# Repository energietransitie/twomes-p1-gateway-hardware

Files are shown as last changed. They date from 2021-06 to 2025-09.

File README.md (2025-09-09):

# Twomes P1 Gateway Hardware

This repository contains the open hardware design files for the Twomes P1 Gateway device, which can read measurement data from a smart meter adhering to the Dutch Smart Meter Requirements (DSMR). It can also receive data from various other Twomes 'satellite' measurement devices via the [ESP-NOW](https://www.espressif.com/en/products/software/esp-now/overview) protocol. The Twomes P1 Gateway can upload this measurement data to a Twomes server via Wi-Fi using secure HTTPS.

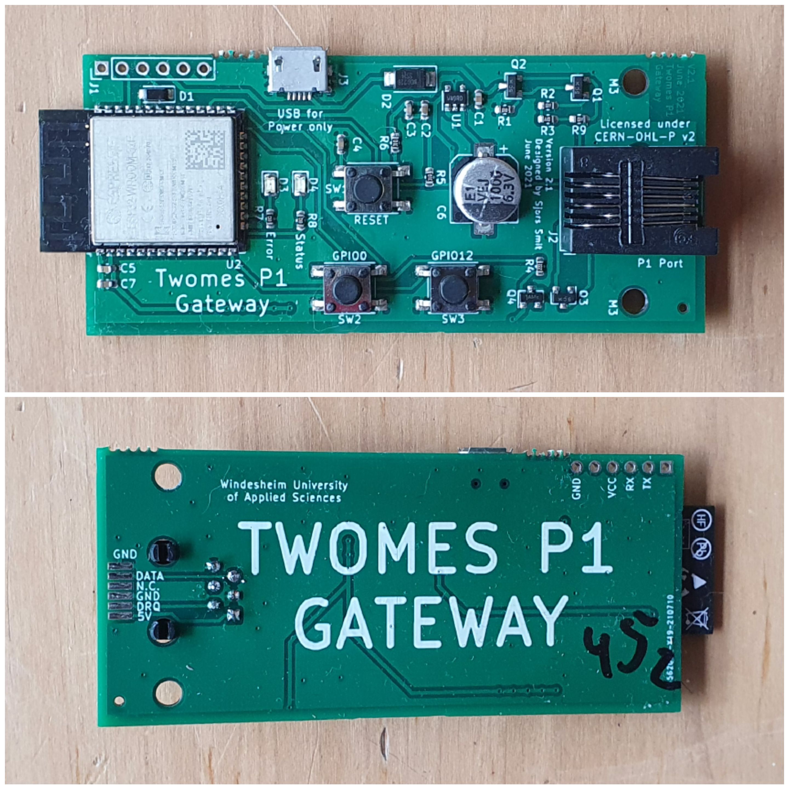
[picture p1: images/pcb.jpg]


## Table of contents
* [General info](#general-info)
* [Producing](#producing)
* [Developing](#developing) 
* [Features](#features)
* [Status](#status)
* [License](#license)
* [Citation](#citation)
* [Credits](#credits)

## General info
This repository contains the source files and fabrication files of the hardware designs of the Twomes P1 Gateway device and its enclosure. It also includes a `docs` folder with recent printouts of the [schematics](./docs/twomes-p1-gateway-sch.pdf) and [PCB layout](./docs/twomes-p1-gateway-pcb.pdf). 

You can run different kinds of firmware on this device:
- [twomes-p1-reader-firmware](https://github.com/energietransitie/twomes-p1-reader-firmware), if you need it to work on a server that supports v2 of the Twomes API.
- [twomes-p1-gateway-firmware](https://github.com/energietransitie/twomes-p1-gateway-firmware), if you need the device to serve as a gateway for the [twomes-room-monitor](https://github.com/energietransitie/twomes-room-monitor-firmware) and/or [twomes-boiler-monitor](https://github.com/energietransitie/twomes-boiler-monitor-firmware).

## Producing

### Printed Circuit Board
To fabricate the printed circuit board you can use various PCB services. 

The folder [pcb/jlcpcb](./pcb/jlcpcb) includes all exported files needed to have the PCBs manufactured by [JLCPCB](https://www.jlcpcb.com). Upload the [zipped gerber files](./pcb/jlcpcb/gerber-TwomesGateway.zip) to the [JLCPCB quote page](https://cart.jlcpcb.com/quote), select the amount of PCBs and a colour for the silkscreen. All other options can be left on default. If SMT assembly is desired, also select this option before ordering. This will take you to a page where the BOM and POS file can be uploaded. Use the files [BOM-TwomesGateway.csv](./pcb/jlcpcb/assembly/BOM-TwomesGateway.csv) and [CPL-TwomesGateway.csv](./pcb/jlcpcb/assembly/BOM-TwomesGateway.csv).

N.B. All components marked "DO NOT PLACE" in the BOM-*.csv file can not be ordered from JLCPCB and need to be ordered from other services and placed manually.

### Enclosure
To fabricate the enclosure you can use your own 3D printer or use a 3D printing service. 

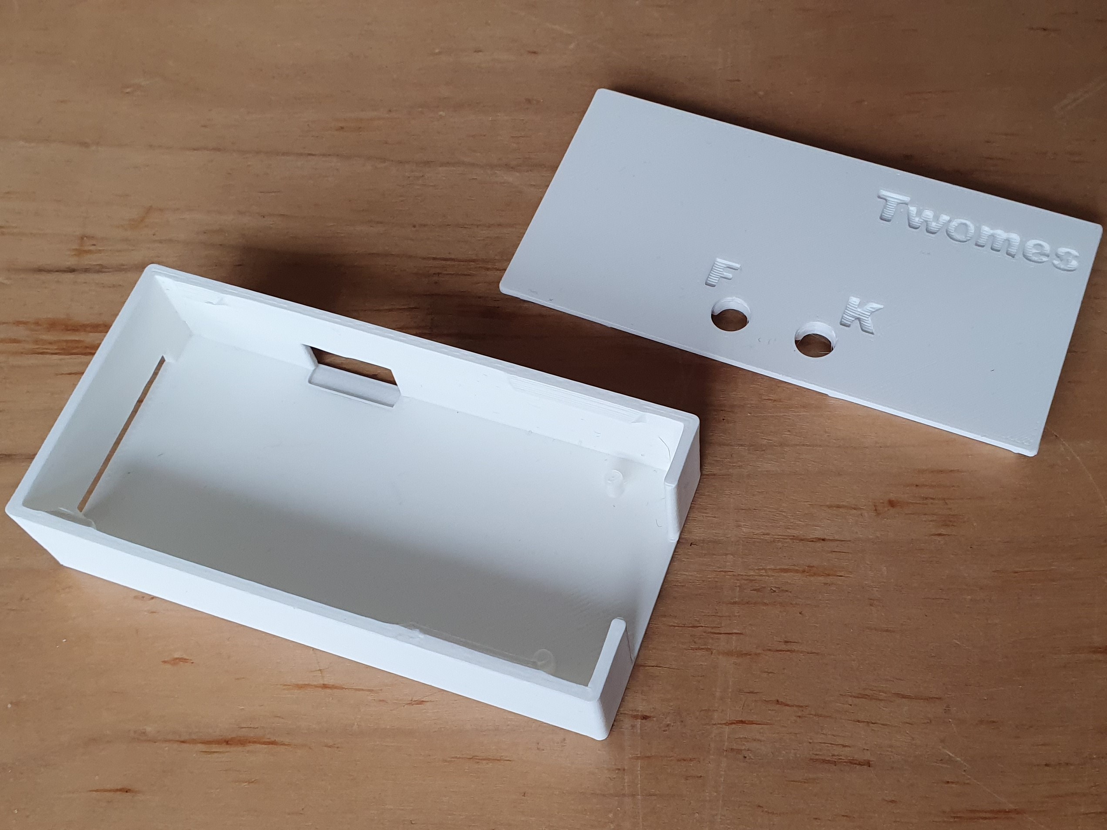
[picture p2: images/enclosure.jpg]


The folder [enclosure/fabrication](./enclosure/fabrication) contains exported STL files for the [case](./enclosure/fabrication/twomes-p1-gateway-enclosure-case.stl), the [lid](./enclosure/fabrication/twomes-p1-gateway-enclosure-lid.stl) and the [button](./enclosure/fabrication/twomes-p1-gateway-enclosure-button.stl) of the Twomes P1-gateway enclosure. The STL files can be imported into any slicer and turned into G-Code for a 3D printer.

## Developing

### Printed Circuit Board
To change the hardware design of the PCB, you need:
* [KiCad](https://www.kicad.org/download/) installed to change te PCB design. 

The KiCad source files of the PCB can be found in the folder [pcb](./pcb).

To convert the PCBs into a format suitable for fabrication, consult the webpage of your PCB manufacturer of choice. For example, see the [JLCPCB guide on how to export Gerbers](https://support.jlcpcb.com/article/149-how-to-generate-gerber-and-drill-files-in-kicad) and the  [JLCPCB guide how to export the BOM and POS files](https://support.jlcpcb.com/article/84-how-to-generate-the-bom-and-centroid-file-from-kicad). You may also use a KiCad plug-in for this purpose such as [kicad-jlcpcb-tools](https://github.com/Bouni/kicad-jlcpcb-tools).

### Enclosure
To change the hardware design of the enclosure, you need either:
* [Autodesk Fusion 360](https://www.kicad.org/download/) installed (Autodesk provides 30 day free trials and [free one-year educational access](https://www.autodesk.com/education/edu-software/overview?sorting=featured&filters=individual) to its products and services for eligible students, teachers and research staff); 
* or [FreeCAD](https://www.freecadweb.org/), an open source alternative.

The source files of the enclosure can be found in the folder [enclosure](./enclosure). We include both .f3d source files and .step source files we obtained after conversion.
## Features
The Twomes P1 Gateway features the following main hardware components:
* [ESP32-WROOM-32E](https://www.espressif.com/sites/default/files/documentation/esp32-wroom-32e_esp32-wroom-32ue_datasheet_en.pdf) module;
* female RJ12 connector for connection to the P1 port of a smart meter adhering to the Dutch Smart Meter Requirements (smart meters compatible with DSMR v5 provide enough power for the Twomes P1 gateway);
* micro USB input for a 5 V power supply (only needed for smart meters adhering to DSMR v4 and lower);
* FTDI compatible serial programming header (3.3 V).

## Status
Project is: _in progress_

## License
The hardware designs in this repository are available under the [CERN-OHL-P v2 license](./LICENSE), Copyright 2022 [Research group Energy Transition, Windesheim University of Applied Sciences](https://windesheim.nl/energietransitie)

## Citation

If you use this repository in your research or work, please cite the following pre-print, which describes the overall NeedForHeat DataGear system of which this repository is a part:

> Ter Hofte, H., & van Ravenzwaaij, N. (2025). *NeedForHeat DataGear: An Open Monitoring System to Accelerate the Residential Heating Transition*. arXiv preprint arXiv:2509.06927. https://doi.org/10.48550/arXiv.2509.06927

**Note:** This is a pre-print submitted on 8 Sep 2025 and has not yet been peer-reviewed. For the full paper, see [https://arxiv.org/abs/2509.06927](https://arxiv.org/abs/2509.06927).

## Credits
This open hardware design made by:
* Sjors Smit · [@Shorts1999](https://github.com/Shorts1999)

Thanks also go to:
* Fredrik-Otto Lautenbag ·  [@Fredrik1997](https://github.com/Fredrik1997)
* Gerwin Buma ·  [@GerwinBuma](https://github.com/GerwinBuma) 
* Marco Winkelman · [@MarcoW71](https://github.com/MarcoW71)

Product owner:
* Marco Winkelman · [@MarcoW71](https://github.com/MarcoW71)

We use and gratefully acknowlegde the efforts of the makers of:
* [KiCad Libraries](https://kicad.github.io/), by the KiCad Development Team, licensed under [an adapted version of the CC-BY-SA 4.0 License](https://www.kicad.org/libraries/license/)

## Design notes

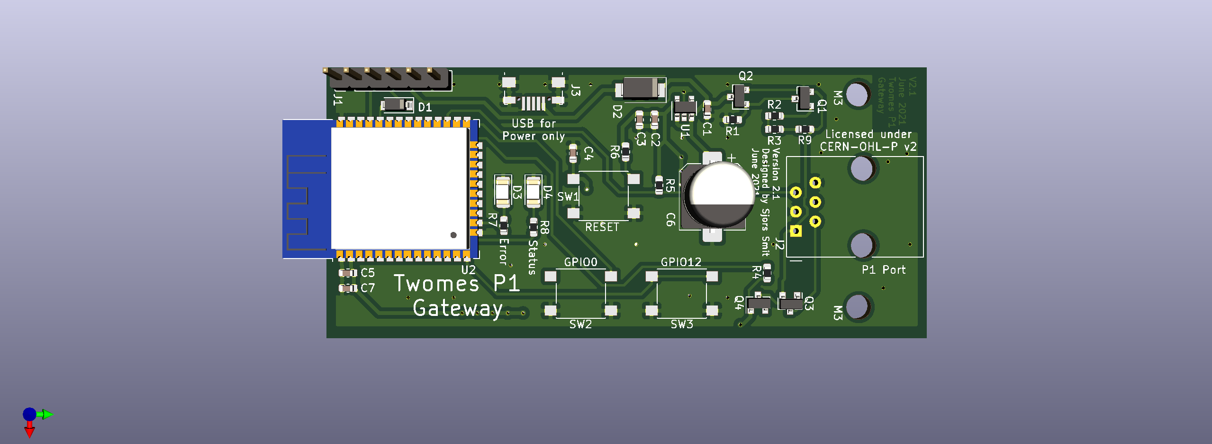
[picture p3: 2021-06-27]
images/twomes-p1-gateway-pcb-top.png

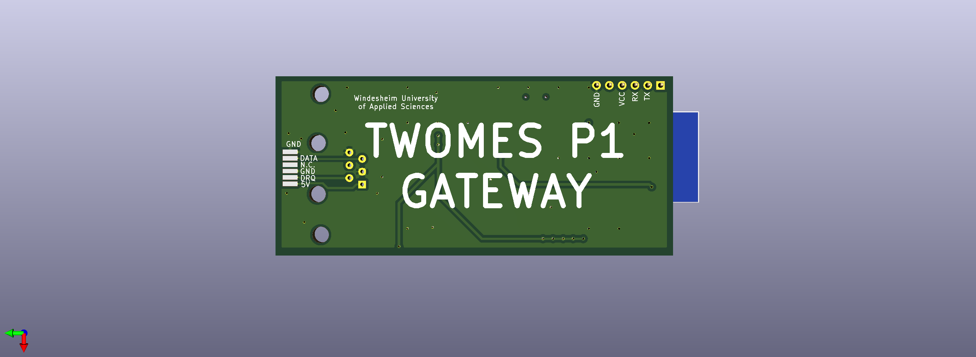
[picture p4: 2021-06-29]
images/twomes-p1-gateway-pcb-3d-bottom.png

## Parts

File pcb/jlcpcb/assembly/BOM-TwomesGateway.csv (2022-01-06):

Comment | Designator | Footprint | LCSC
1uF | C1,C2 | Capacitor_SMD:C_0603_1608Metric | C15849
10uF | C7 | Capacitor_SMD:C_0603_1608Metric | C19702
100nF | C3,C4,C5 | Capacitor_SMD:C_0603_1608Metric | C14663
1000uF | C6 | Capacitor_SMD:CP_Elec_8x10.5 | C134755
1N4148W | D1 | Diode_SMD:D_SOD-123 | C81598
SS14 | D2 | Diode_SMD:D_SMA | C2480
LED_RED | D3 | LED_SMD:LED_1206_3216Metric | C84256
LED_GREEN | D4 | Diode_SMD:D_0805_2012Metric | C2297
FTDI header | J1 | Connector_PinHeader_2.54mm:PinHeader_1x06_P2.54mm_Vertical | DO NOT PLACE
RJ12-6P6C | J2 | Connector_RJ:RJ12_Amphenol_54601 | DO NOT PLACE
USB_B_Micro | J3 | Connector_USB:USB_Micro-B-SHOUHAN_QTJ | C404968
BC807 | Q1,Q2,Q3 | Package_TO_SOT_SMD:SOT-23 | C82369
MMBT3904 | Q4 | Package_TO_SOT_SMD:SOT-23 | C20526
1k | R1,R7,R8 | Resistor_SMD:R_0603_1608Metric | C21190
1R | R2,R3,R9 | Resistor_SMD:R_0603_1608Metric | C22936
2.2k | R4 | Resistor_SMD:R_0603_1608Metric | C4190
10k | R5,R6 | Resistor_SMD:R_0603_1608Metric | C25804
SW_Push | SW1,SW2,SW3 | Button_Switch_SMD:SW_Push_1P1T_NO_6x6mm_H9.5mm | C83206
AP7365-33WG-7 | U1 | Package_TO_SOT_SMD:SOT-23-5 | C150742
ESP32-WROOM-32E | U2 | RF_Module:ESP32-WROOM-32 | C701343

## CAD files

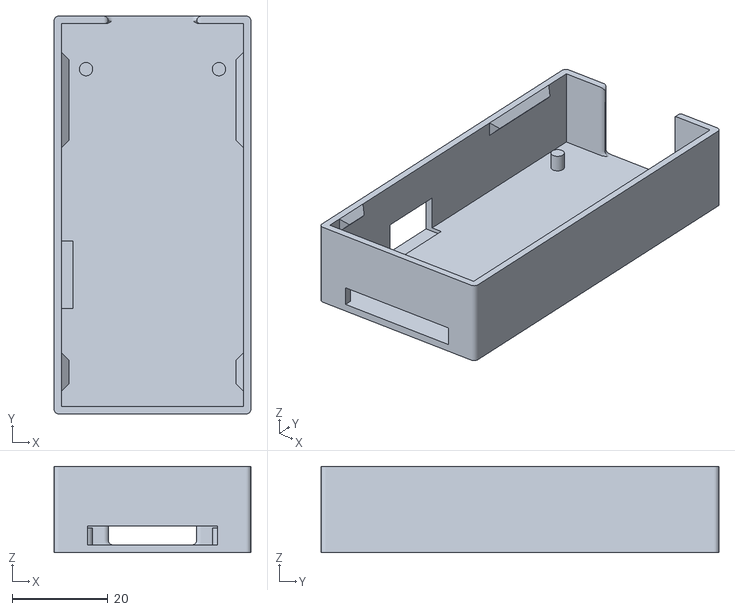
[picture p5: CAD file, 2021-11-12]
enclosure/fabrication/twomes-p1-gateway-enclosure-case.stl
41.2 x 83.2 x 18.0

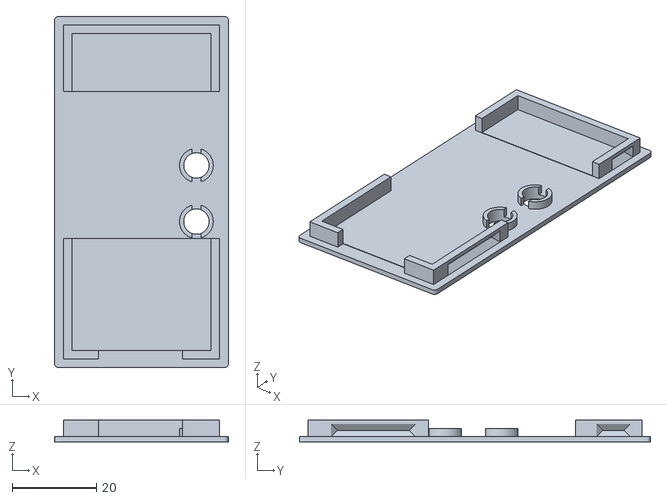
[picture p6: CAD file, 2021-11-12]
enclosure/fabrication/twomes-p1-gateway-enclosure-lid.stl
41.2 x 83.2 x 5.10

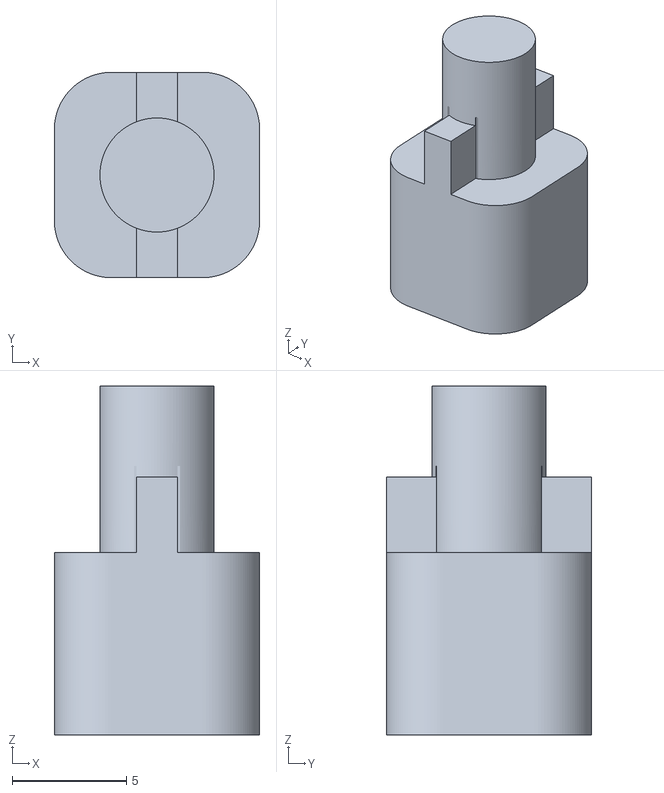
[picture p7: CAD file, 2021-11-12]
enclosure/fabrication/twomes-p1-gateway-enclosure-button.stl
9.00 x 9.00 x 15.3

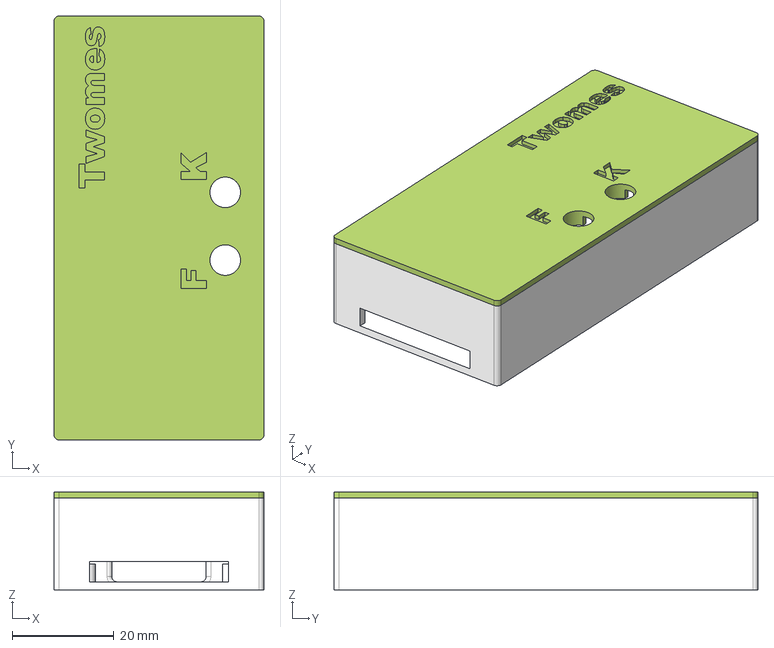
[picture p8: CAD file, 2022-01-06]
enclosure/twomes-p1-gateway-enclosure.step
41.2 x 83.2 x 19.2 mm

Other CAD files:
enclosure/twomes-p1-gateway-enclosure-case.step
enclosure/twomes-p1-gateway-enclosure-lid.step
enclosure/twomes-p1-gateway-button.step
enclosure/twomes-p1-gateway-button.f3d
enclosure/twomes-p1-gateway-enclosure.f3d

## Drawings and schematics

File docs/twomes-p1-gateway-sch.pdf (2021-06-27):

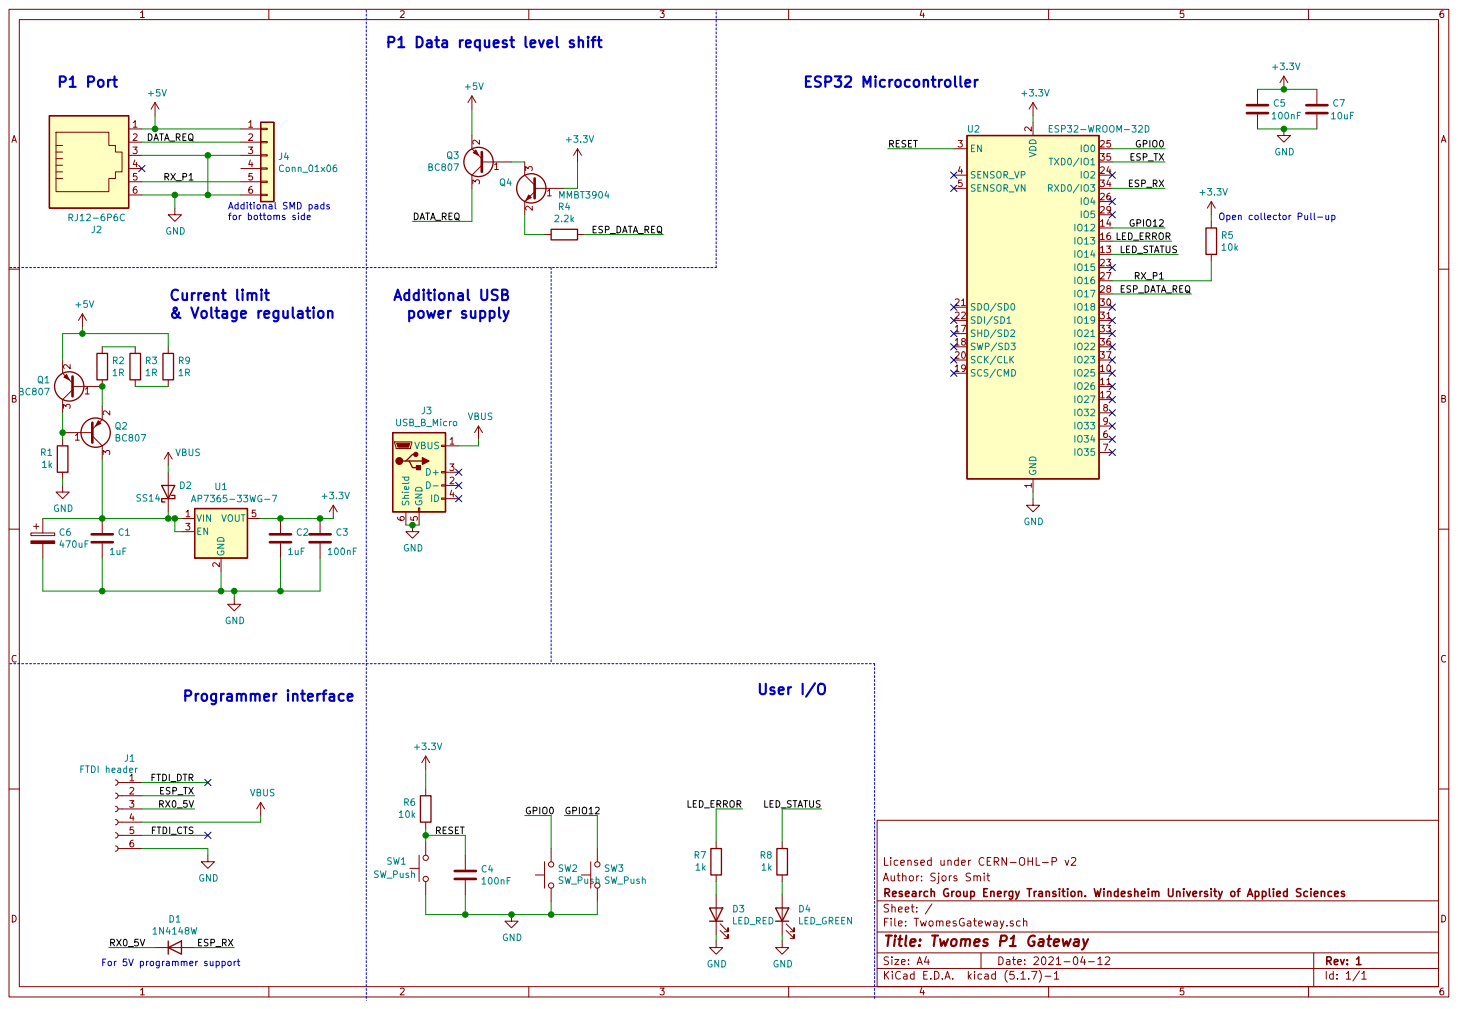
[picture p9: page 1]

P1 Data request level shift

2 SCK/CLK 20 SDO/SD0 21 SDI/SD1 22

Open collector Pull-up

Author: Sjors Smit Licensed under CERN-OHL-P v2 D2 SS14 D1

File: TwomesGateway.sch Sheet: / Research Group Energy Transition. Windesheim University of Applied Sciences

Id: 1/1 Title: Twomes P1 Gateway

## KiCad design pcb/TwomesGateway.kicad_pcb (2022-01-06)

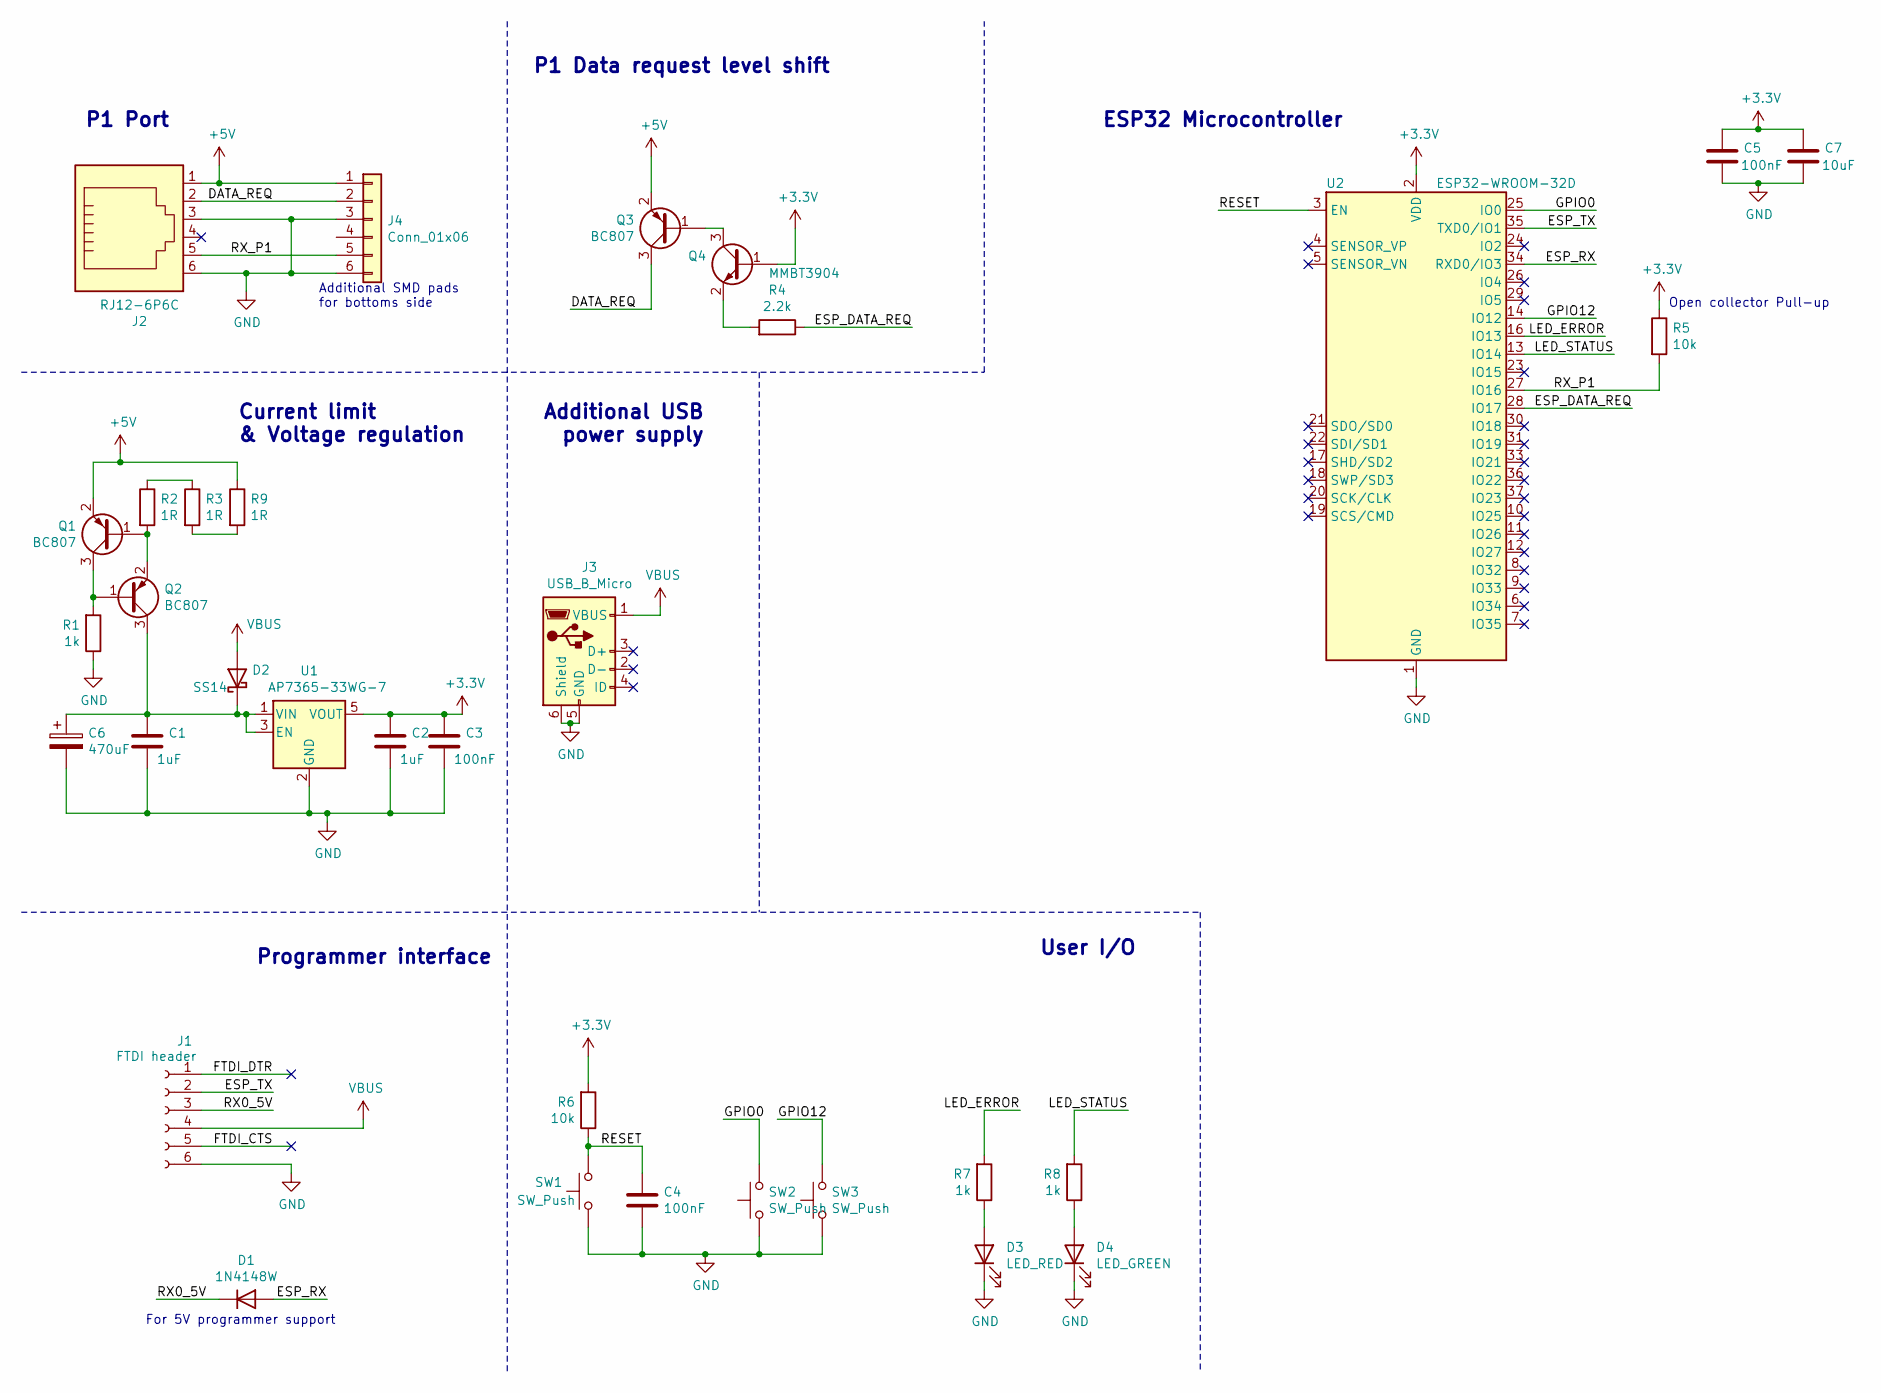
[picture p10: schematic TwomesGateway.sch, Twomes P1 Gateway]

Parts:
C1, C2: 1uF; C_0603_1608Metric
C3, C4, C5: 100nF; C_0603_1608Metric
C6: 470uF; CP_Elec_8x10.5
C7: 10uF; C_0603_1608Metric
D1: 1N4148W; D_SOD-123
D2: SS14; D_SOD-123
D3: LED_RED; LED_1206_3216Metric
D4: LED_GREEN; D_0805_2012Metric
J1: FTDI header; PinHeader_1x06_P2.54mm_Vertical
J2: RJ12-6P6C; RJ12_Amphenol_54601
J3: USB_B_Micro; ÙSB_JLC__SHOUHAN_microQTJ
J4: Conn_01x06; Rj12SMD
Q1, Q2, Q3: BC807; SOT-23
Q4: MMBT3904; SOT-23
R1, R7, R8: 1k; R_0603_1608Metric
R2, R3, R9: 1R; R_0603_1608Metric
R4: 2.2k; R_0603_1608Metric
R5, R6: 10k; R_0603_1608Metric
SW1, SW2, SW3: SW_Push; SW_Push_1P1T_NO_6x6mm_H9.5mm
U1: AP7365-33WG-7; SOT-23-5
U2: ESP32-WROOM-32D; ESP32-WROOM-32

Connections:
+3V3: C2.1, C3.1, C5.1, C7.1, Q4.1 (B), R5.1, R6.2, U1.5 (VOUT), U2.2 (VDD)
+5V: J2.1, J4.1, Q1.2 (E), Q3.2 (E), R9.1
/DATA_REQ: J2.2, J4.2, Q3.3 (C)
/ESP_DATA_REQ: R4.1, U2.28 (IO17)
/ESP_RX: D1.2 (A), U2.34 (RXD0/IO3)
/ESP_TX: J1.2, U2.35 (TXD0/IO1)
/FTDI_CTS: J1.5
/FTDI_DTR: J1.1
/GPIO0: SW2.2, U2.25 (IO0)
/GPIO12: SW3.2, U2.14 (IO12)
/LED_ERROR: R7.2, U2.16 (IO13)
/LED_STATUS: R8.2, U2.13 (IO14)
/RESET: C4.1, R6.1, SW1.2, U2.3 (EN)
/RX0_5V: D1.1 (K), J1.3
/RX_P1: J2.5, J4.5, R5.2, U2.27 (IO16)
GND: C1.2, C2.2, C3.2, C4.2, C5.2, C6.2, C7.2, D3.1 (K), D4.1 (K), J1.6, J2.3, J2.6, J3.5 (GND), J3.6 (Shield), J4.3, J4.6, R1.1, SW1.1, SW2.1, SW3.1, U1.2 (GND), U2.1 (GND), U2.15 (GND), U2.38 (GND), U2.39 (GND)
unnamed: C1.1, C6.1, D2.1 (K), Q2.3 (C), U1.1 (VIN), U1.3 (EN)
unnamed: D3.2 (A), R7.1
unnamed: D4.2 (A), R8.1
unnamed: Q1.1 (B), Q2.2 (E), R2.2
unnamed: Q1.3 (C), Q2.1 (B), R1.2
unnamed: Q3.1 (B), Q4.3 (C)
unnamed: Q4.2 (E), R4.2
unnamed: R2.1, R3.1
unnamed: R3.2, R9.2
VBUS: D2.2 (A), J1.4, J3.1 (VBUS)

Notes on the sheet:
Current limit & Voltage regulation
P1 Port
Programmer interface
For 5V programmer support
Additional USB power supply
P1 Data request level shift
Open collector Pull-up
ESP32 Microcontroller
User I/O
Additional SMD pads for bottoms side

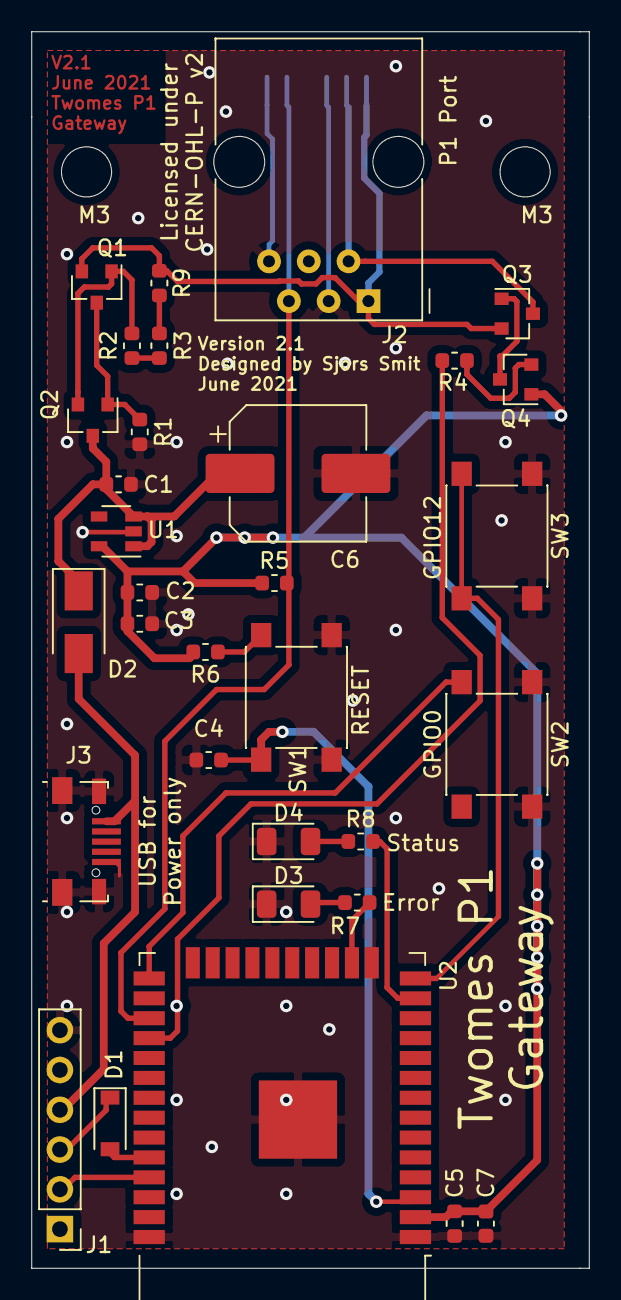
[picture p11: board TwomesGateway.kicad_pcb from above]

Board: 2 copper layers, 35.6 x 79.0 mm, 35 parts (1 on the bottom side), 24 nets.

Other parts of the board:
M3, M3#2: MountingHole_3.2mm_M3

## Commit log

2021-06-27 Upload 3D models for enclosures
    [ButtonCap.f3d, GatewayCase.f3d, GatewayTop.stl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]
2021-11-12 Update to new enclosure folder structure
    [ButtonCap.f3d, GatewayCase.f3d, GatewayTop.stl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]
2021-11-12 New cases with double button and letter names
    [GatewayButton.f3d, GatewayButton.stl, GatewayCase.stl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]
2021-12-29 change structure
    [BOM_TwomesGatewayJLCPCB.csv, GatewayButton.f3d, GatewayButton.stl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]
2021-12-29 fix typos and add KiCad Libraries in credits
2022-01-04 update pcb image
2022-01-06 reorganized files needed for fabrication; updated README
    [BOM_TwomesGatewayJLCPCB.csv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]
2022-01-06 add BOM and CPL files in assembly subfolder
    [BOM-TwomesGateway.csv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]
2022-04-01 Update README.md
    fixed ESP32 module actually used
